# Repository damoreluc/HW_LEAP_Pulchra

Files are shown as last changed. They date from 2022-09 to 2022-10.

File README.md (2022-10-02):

# HW_LEAP_Pulchra
File del progetto HW Leap Pulchra

## Scheda della stazione meteo con Arduino MKRWAN1310

__Connettori:__

* X1: direzione vento (X1-1: +3V3; X1-2: tensione analogica tra 0V e +3V3; X1-3: GND)
* X2: anemometro (X2-1: +3V3; X2-2: impulsi, open drain; X2-3: GND)
* X3: alimentazione +3V3 (X3-1: +3V3; X3-2: GND)
* X4: pluviometro (X4-1: +3V3; X4-2: impulsi bilancere, open drain; X4-3 +12V riscaldatore neve; X4-4: GND riscaldatore neve)
* X5: alimentazione +12V (X5-1: +12V; X5-2: GND)
* X6: ventola interna all'armadietto (X6-1: +12V; X6-2: comando PWM ventola, collettore transistor Q1)
* X8: sensore bagnatura foglia (X8-1: +3V3; X8-2: on/off, open drain; X8-3; GND)

---

__Componenti e sensori integrati onboard:__
* U1: scheda microcontrollore e radio MKRWAN1310
* U2: modulo condizionamento per sensore esterno di temperatura PT100, ADAFRUIT_MX31865
* U3: (opzionale) sensore temperatura e umidità interno BME280
* U4: (opzionale) display oled SSD1306_128X64
* U5: (opzionale) sensore di temperatura interna analogico TMP36

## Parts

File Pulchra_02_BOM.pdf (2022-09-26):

26/09/22, 18:47 | Pulchra_02_BOM.html
file:///C:/Users/luca/Documents/EAGLE/projects/PULCHRA/Pulchra_02/Pulchra_02_BOM.html | 1/1

Partlist exported from C:/Users/luca/Documents/EAGLE/projects/PULCHRA/Pulchra_02/Pulchra_02.sch at 26/09/2022 18:45

Qty Value | Device | Package | Parts Description | MF | MPN | OC_FARNELL OC_NEWARK POPULARITY SPICEPREFIX
1 | 1.5K | R-EU_0207/10 | 0207/10 | R3 | RESISTOR, European symbol | 81 | R
2 | 100nF | C-EU050-025X075 | C050-025X075 | C1,
| | | | C2 | CAPACITOR, European symbol | 29 | C
1 | 10K | R-EU_0207/10 | 0207/10 | R11 RESISTOR, European symbol | 81 | R
3 | 12K | R-EU_0207/10 | 0207/10 | R1,
| | | | R2,
| | | | R6 | RESISTOR, European symbol | 81 | R
1 | 1N4004 | 1N4004 | DO41-10 | D2 | DIODE | 82
1 | 1N5819-B | 1N5819-B | DO41-7.6 | D1 | 1.0A SCHOTTKY BARRIER
| | | | | RECTIFIER | 11
1 | 33K | R-EU_0207/10 | 0207/10 | R4 | RESISTOR, European symbol | 81 | R
1 | 470nF | C-EU050-025X075 | C050-025X075 | C3 | CAPACITOR, European symbol | 29 | C
1 | ADAFRUIT_MX31865 ADAFRUIT_MX31865 ADAFRUIT_MAX31865 U$2
| | | | | Adafruit MAX31865 - Adafruit
| | | | | MAX31865 RTD PT100 or
| | | | | PT1000 Amplifier
1 | BD677 | BD677 | TO126 | Q1 | NPN Darlington Transistor | 0
1 | BME280 | BME280 | BME280_GYBMEP | U$3
1 | MKRWAN1310 | MKRWAN1310 | MKRWAN1310 | U$1 Arduino MKR WAN 1310 -
| | | | | Code: MKRWAN1310WANT
1 | MOUNT-PAD-
| ROUND4.1 | MOUNT-PAD-
| | ROUND4.1 | 4,1-PAD | H1 | MOUNTING PAD, round | 0
3 | MST2V | MST2V | MSTBV2 | X3,
| | | | X5,
| | | | X6
PHOENIX | unknown | unknown | 0
3 | MSTBA3 | MSTBA3 | MSTBA3 | X1,
| | | | X2,
| | | | X8
PHOENIX | FARNELL 1757255 3705183 | 71C4162 | 3
1 | MSTBV4 | MSTBV4 | MSTBV4 | X4 | PHOENIX

MSTBV
2,5/4-GF-5.08
1792794 | 69R9847 | 2
1 | SSD1306_128X64 | SSD1306_128X64 | 128X64 | U$4 | OLED Display Board 0.91"
| | | | | 128x64 White I2C - 4 Pins -
| | | | | SSD1306
1 | TMP36 | TMP36 | TO92 | U$5 | TMP35, TMP36, TMP37 - low
| | | | | voltage, precision centigrade
| | | | | temperature sensors

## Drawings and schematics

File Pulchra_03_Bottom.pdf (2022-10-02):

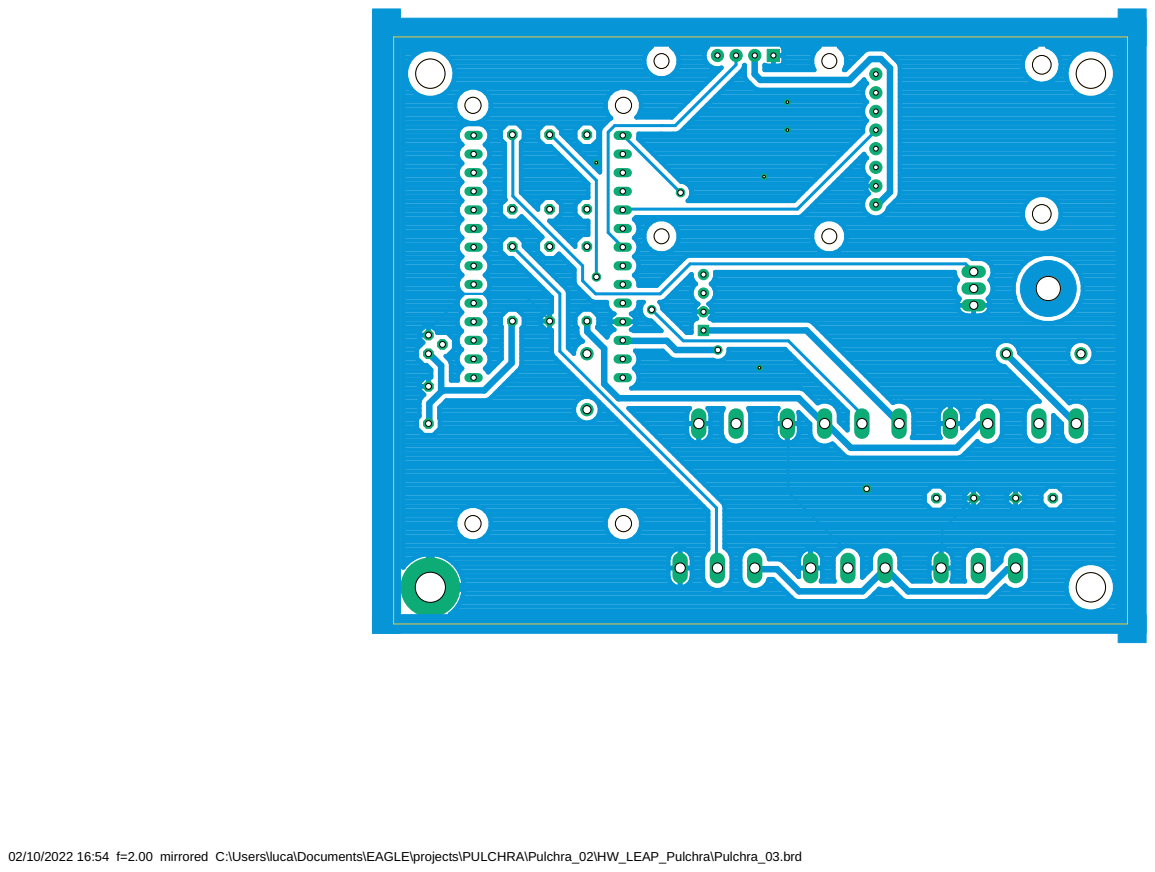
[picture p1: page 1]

02/10/2022 16:54 f=2.00 mirrored C:\Users\luca\Documents\EAGLE\projects\PULCHRA\Pulchra_02\HW_LEAP_Pulchra\Pulchra_03.brd

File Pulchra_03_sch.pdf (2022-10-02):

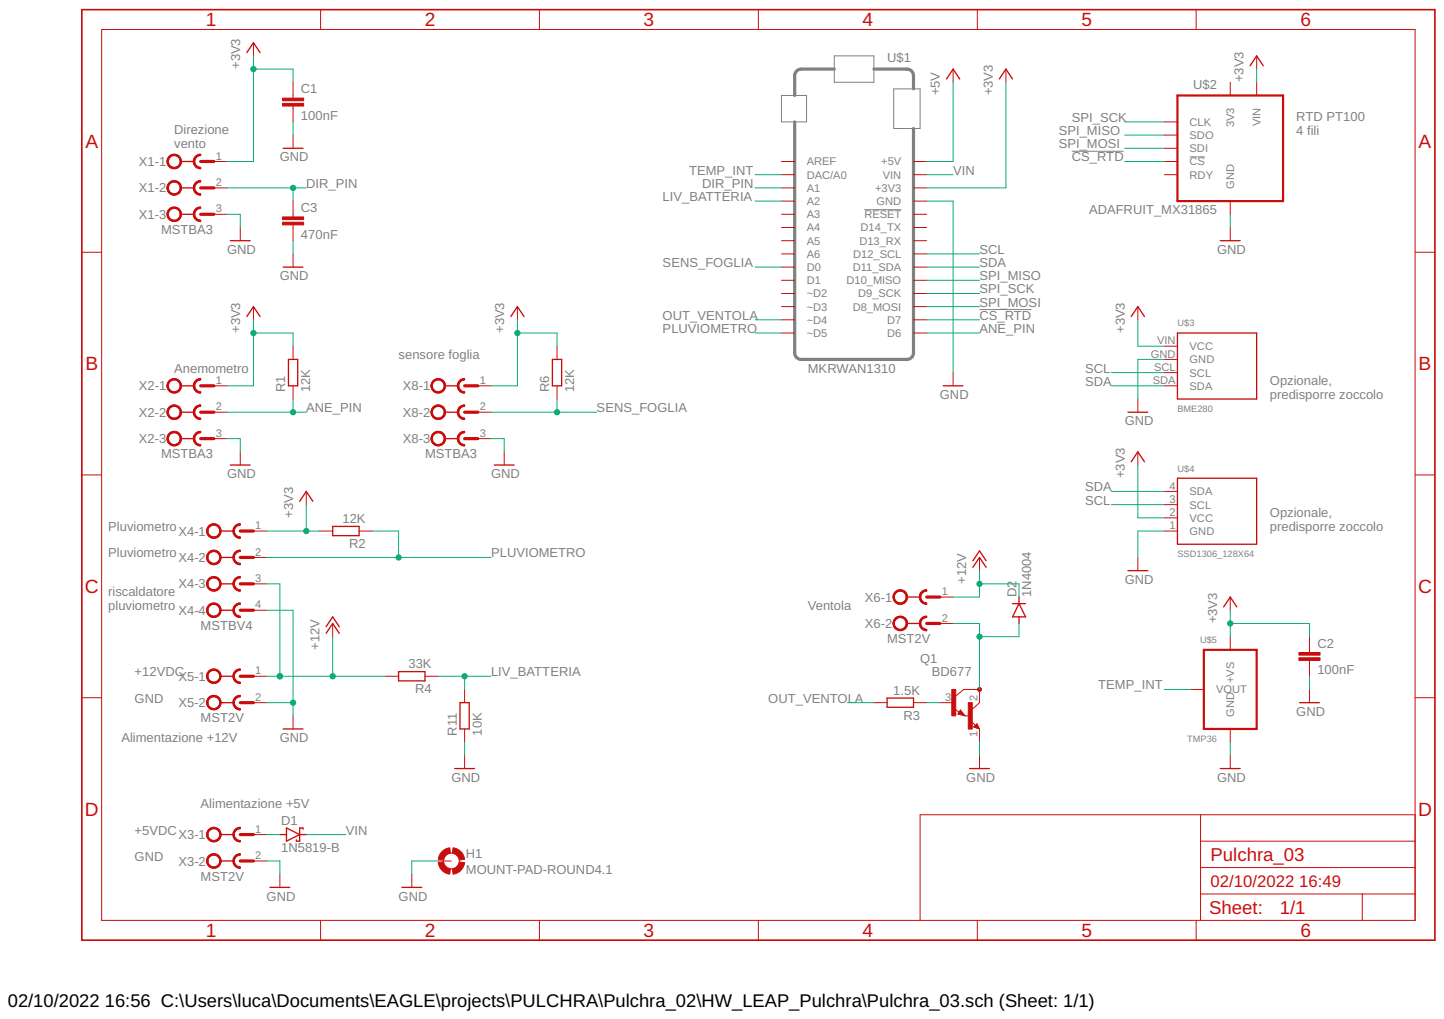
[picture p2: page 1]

Opzionale, predisporre zoccolo

02/10/2022 16:56 C:\Users\luca\Documents\EAGLE\projects\PULCHRA\Pulchra_02\HW_LEAP_Pulchra\Pulchra_03.sch (Sheet: 1/1)

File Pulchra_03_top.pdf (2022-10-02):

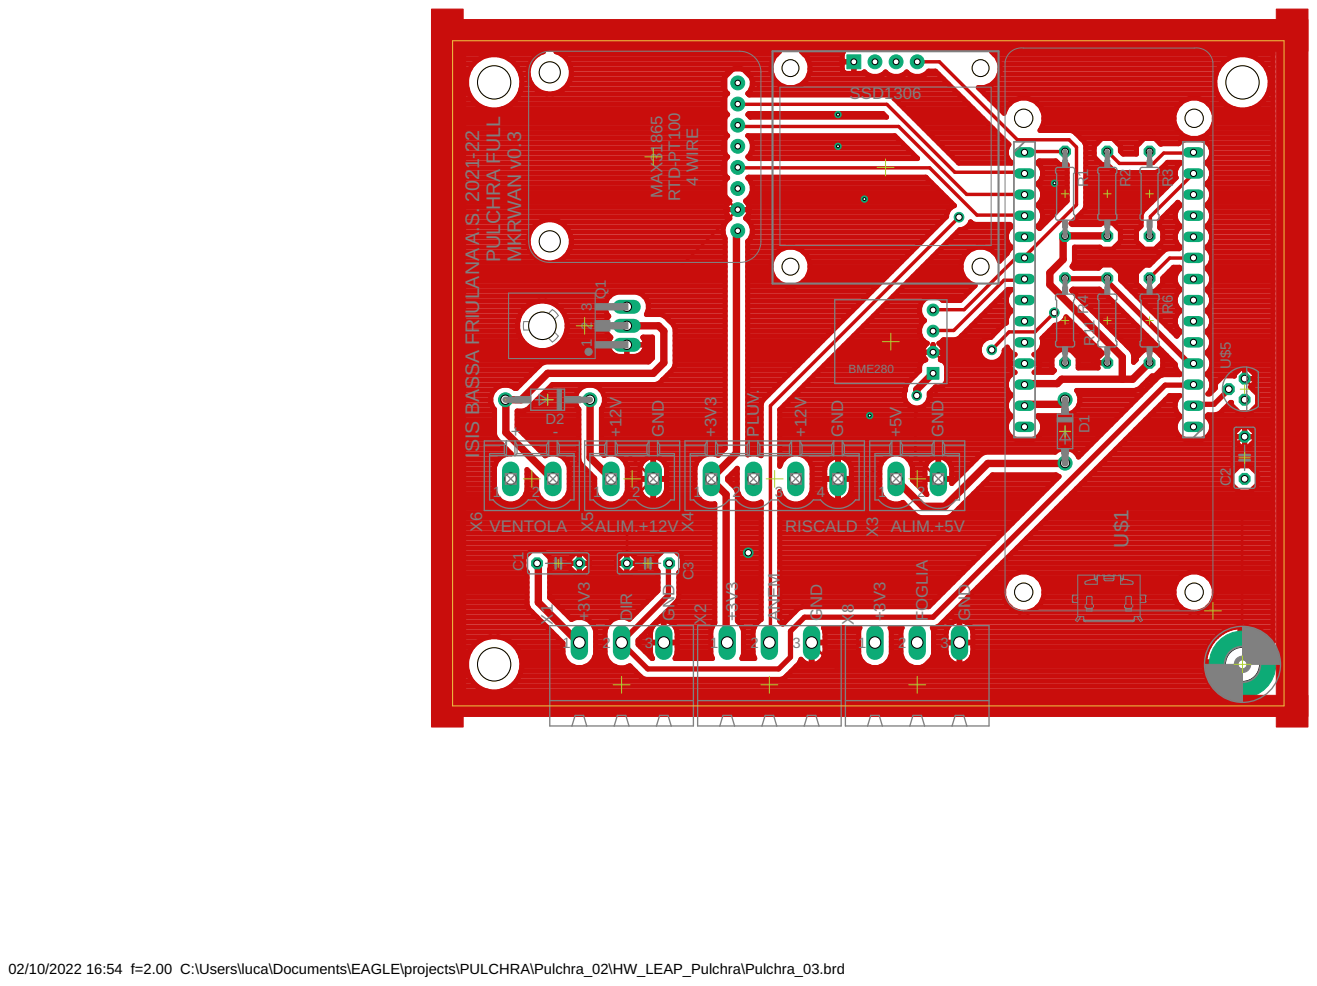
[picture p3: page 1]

02/10/2022 16:54 f=2.00 C:\Users\luca\Documents\EAGLE\projects\PULCHRA\Pulchra_02\HW_LEAP_Pulchra\Pulchra_03.brd

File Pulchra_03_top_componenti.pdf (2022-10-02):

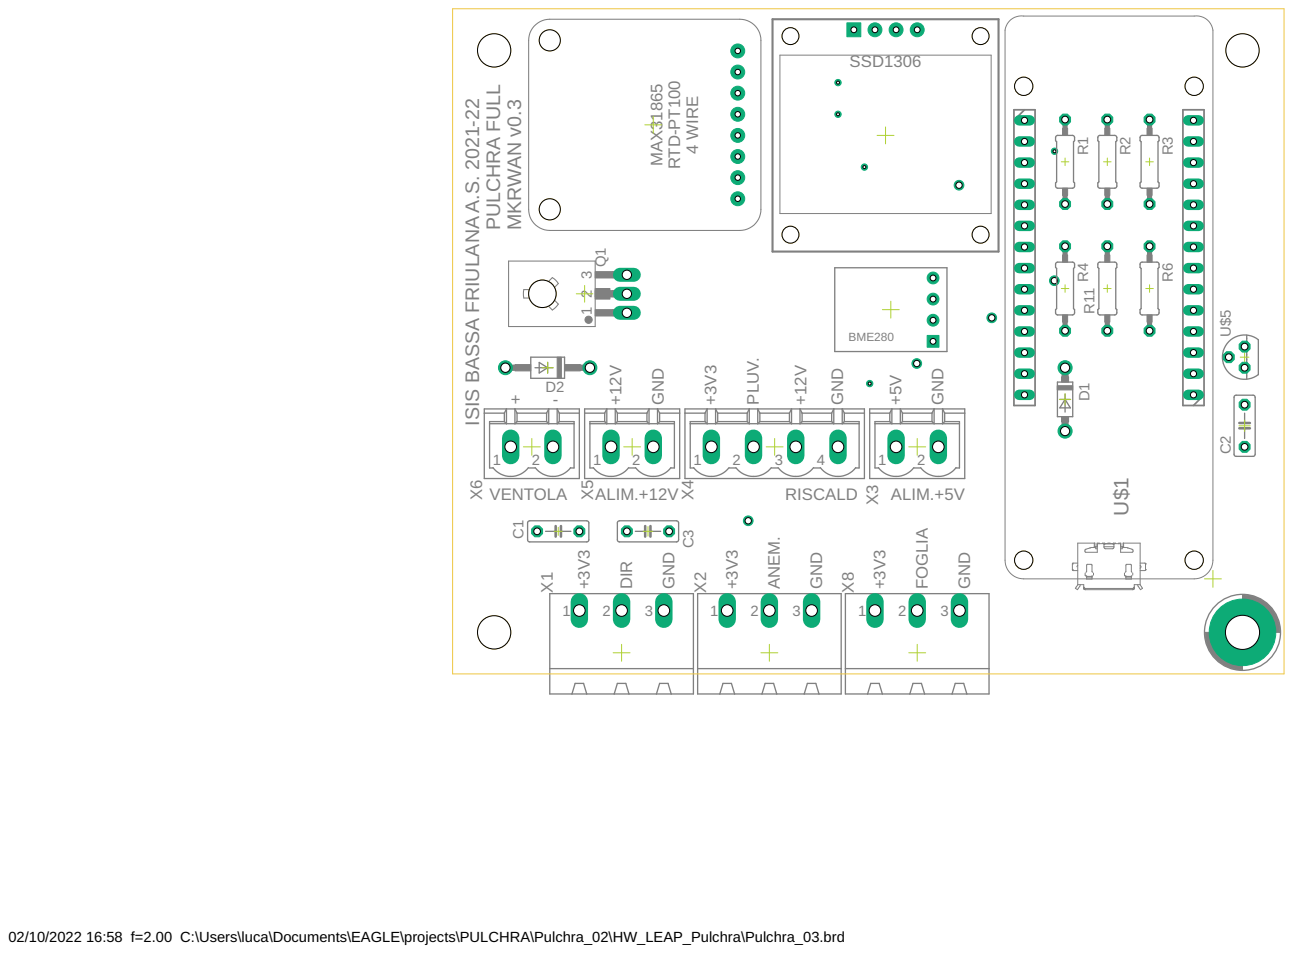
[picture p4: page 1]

02/10/2022 16:58 f=2.00 C:\Users\luca\Documents\EAGLE\projects\PULCHRA\Pulchra_02\HW_LEAP_Pulchra\Pulchra_03.brd

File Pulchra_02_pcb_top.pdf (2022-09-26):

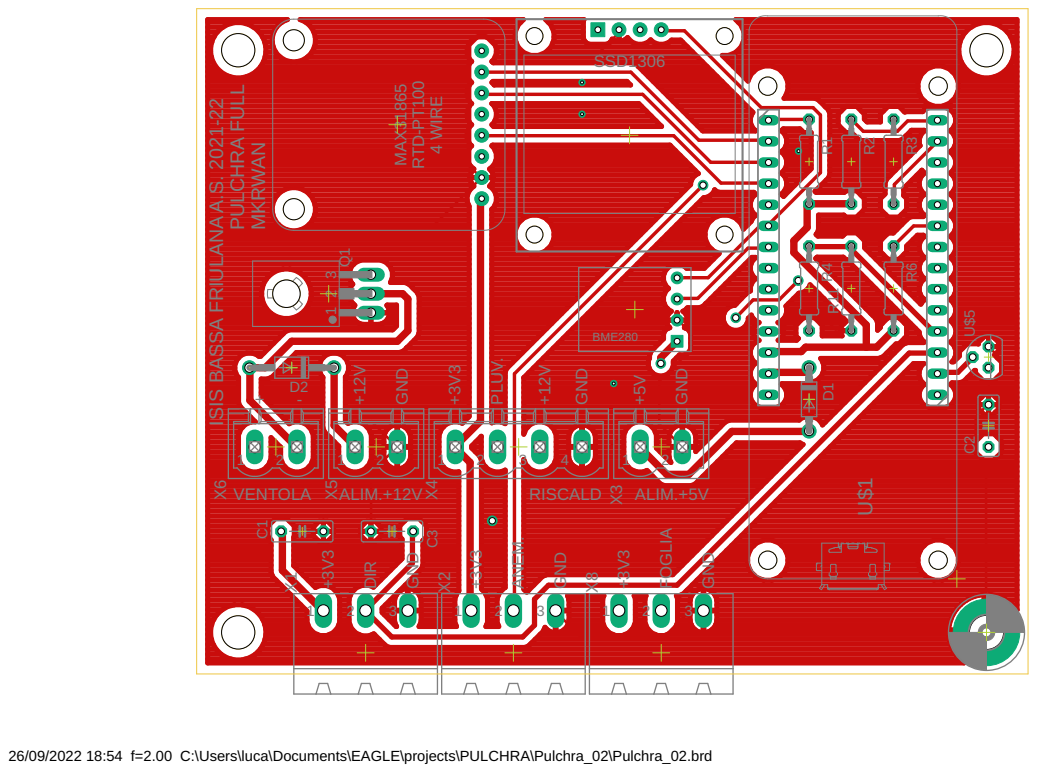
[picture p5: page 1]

26/09/2022 18:54 f=2.00 C:\Users\luca\Documents\EAGLE\projects\PULCHRA\Pulchra_02\Pulchra_02.brd

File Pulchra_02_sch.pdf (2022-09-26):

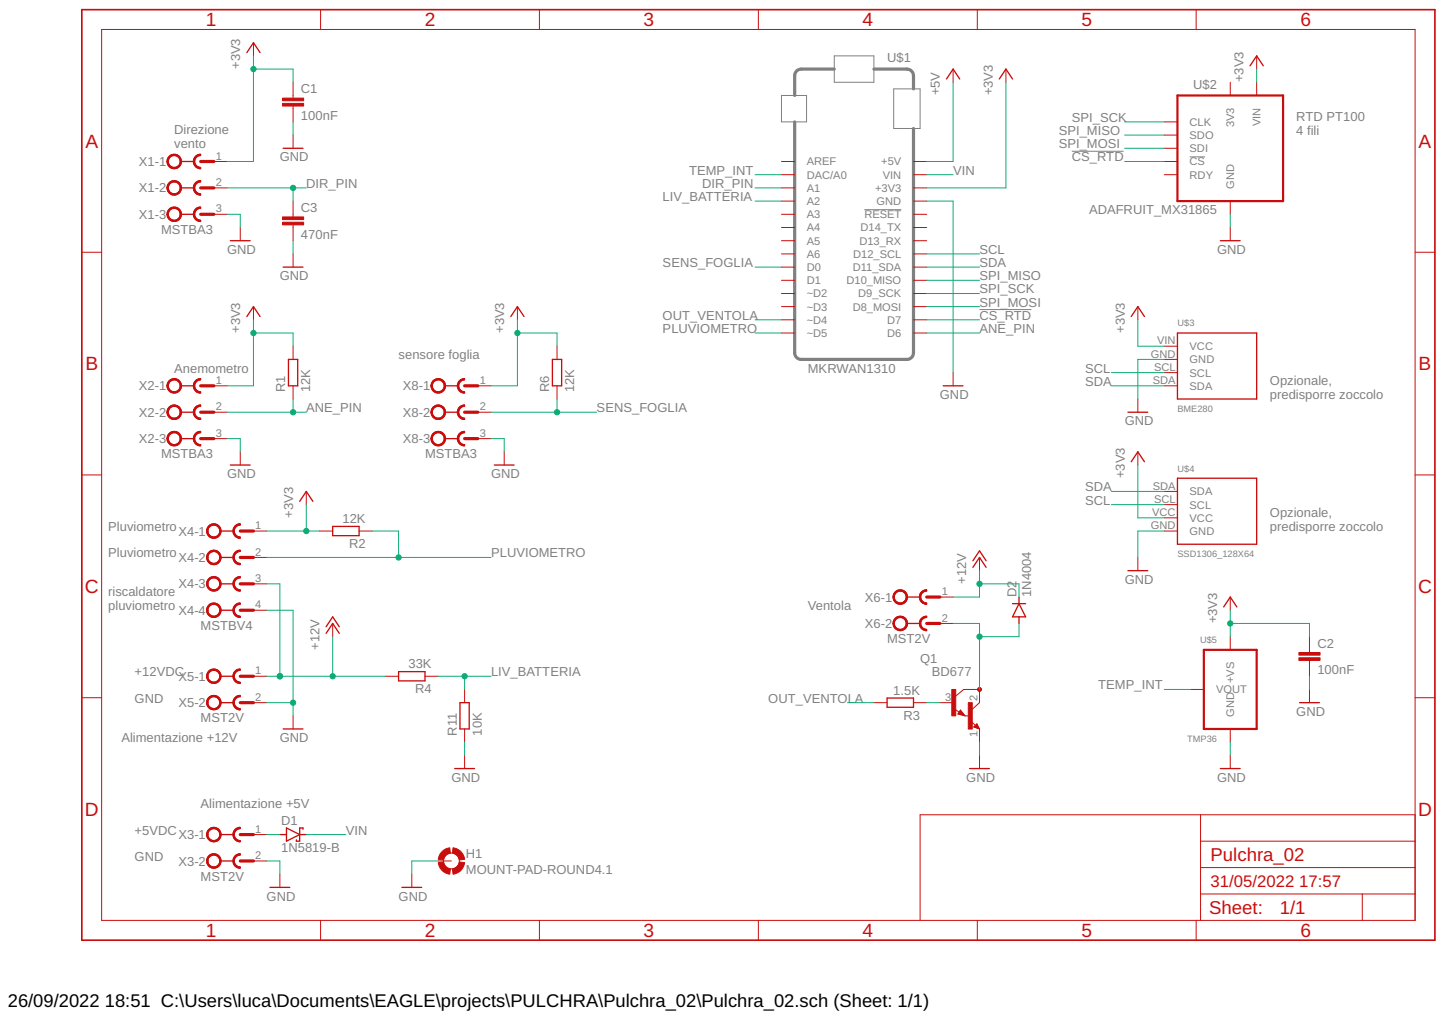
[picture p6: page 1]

Opzionale, predisporre zoccolo

26/09/2022 18:51 C:\Users\luca\Documents\EAGLE\projects\PULCHRA\Pulchra_02\Pulchra_02.sch (Sheet: 1/1)

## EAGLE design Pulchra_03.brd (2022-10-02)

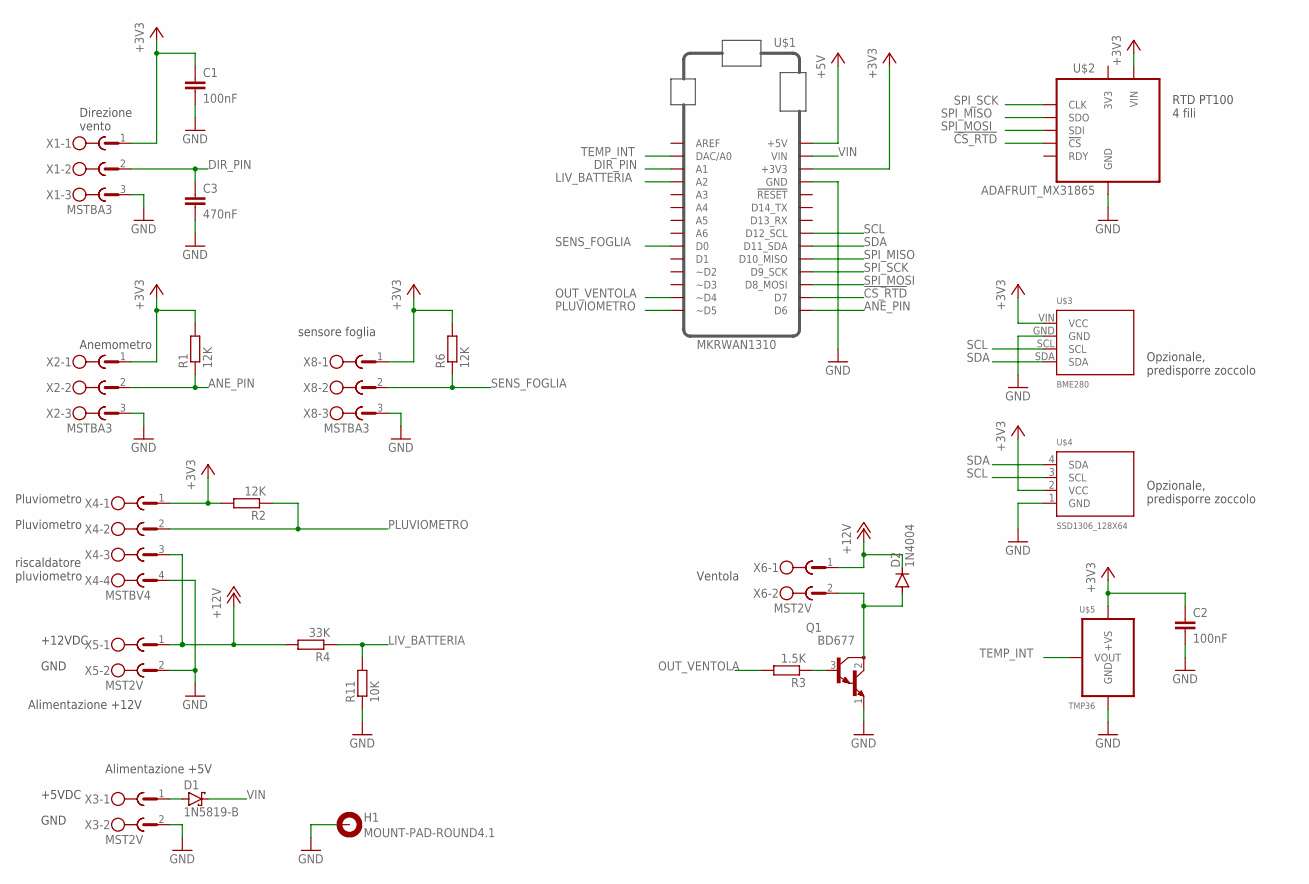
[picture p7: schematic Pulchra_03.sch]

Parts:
C1, C2: 100nF; C050-025X075
C3: 470nF; C050-025X075
D1: 1N5819-B; DO41-7.6
D2: 1N4004; DO41-10
H1: MOUNT-PAD-ROUND4.1; 4,1-PAD
Q1: BD677; TO126
R1, R2, R6: 12K; 0207/10
R3: 1.5K; 0207/10
R4: 33K; 0207/10
R11: 10K; 0207/10
U$1: MKRWAN1310
U$2: ADAFRUIT_MX31865; ADAFRUIT_MAX31865
U$3: BME280; BME280_GYBMEP
U$4: SSD1306_128X64; 128X64
U$5: TMP36; TO92
X1, X2, X8: MSTBA3
X3, X5, X6: MST2V; MSTBV2
X4: MSTBV4

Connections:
!CS_RTD!: U$1.D7, U$2.P7 (!CS!)
+3V3: C1.1, C2.1, R1.2, R2.2, R6.2, U$1.+3V3, U$2.P1 (VIN), U$3.VIN (VCC), U$4.2 (VCC), U$5.1 (+VS), X1.1, X2.1, X4.1, X8.1
+5V: U$1.+5V
+12V: D2.C, R4.2, X4.3, X5.1, X6.1
ANE_PIN: R1.1, U$1.D6, X2.2
DIR_PIN: C3.1, U$1.A1, X1.2
GND: C1.2, C2.2, C3.2, H1.B4,1, Q1.1 (E), R11.1, U$1.GND, U$2.P2 (GND), U$3.GND, U$4.1 (GND), U$5.3 (GND), X1.3, X2.3, X3.2, X4.4, X5.2, X8.3
LIV_BATTERIA: R4.1, R11.2, U$1.A2
unnamed: Q1.3 (B), R3.1
unnamed: D1.A, X3.1
unnamed: D2.A, Q1.2 (C), X6.2
OUT_VENTOLA: R3.2, U$1.~D4
PLUVIOMETRO: R2.1, U$1.~D5, X4.2
SCL: U$1.D12_SCL, U$3.SCL, U$4.3 (SCL)
SDA: U$1.D11_SDA, U$3.SDA, U$4.4 (SDA)
SENS_FOGLIA: R6.1, U$1.D0, X8.2
SPI_MISO: U$1.D10_MISO, U$2.P5 (SDO)
SPI_MOSI: U$1.D8_MOSI, U$2.P6 (SDI)
SPI_SCK: U$1.D9_SCK, U$2.P4 (CLK)
TEMP_INT: U$1.DAC0/A0 (DAC/A0), U$5.2 (VOUT)
VIN: D1.C, U$1.VIN

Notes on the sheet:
Opzionale, predisporre zoccolo
Direzione vento
Anemometro
Alimentazione +5V
Pluviometro
Ventola
sensore foglia
Alimentazione +12V
+5VDC
+12VDC
GND
RTD PT100 4 fili
riscaldatore pluviometro

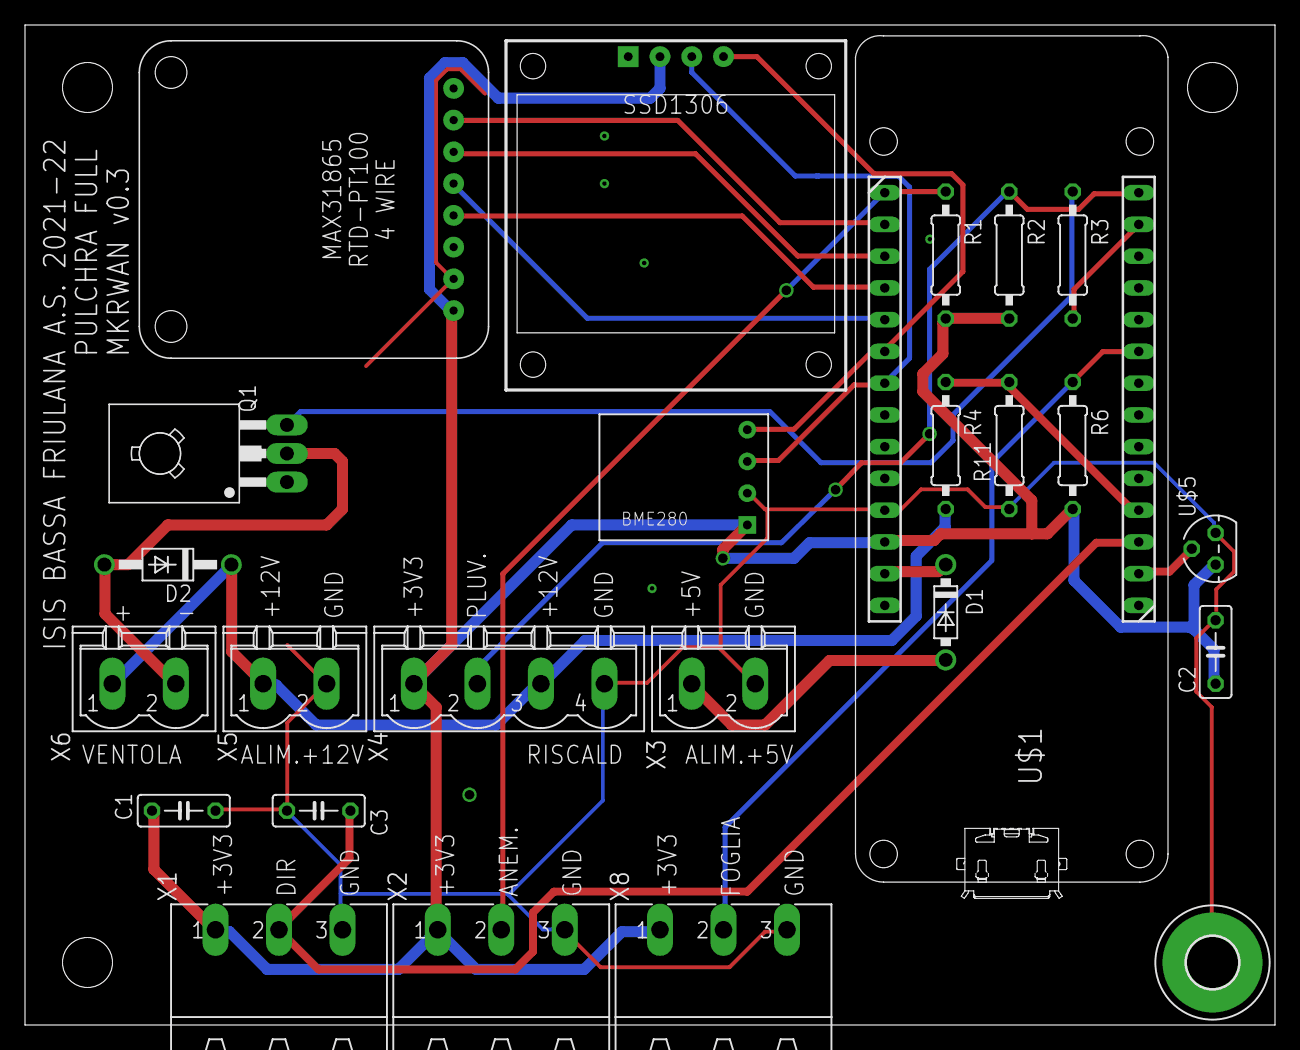
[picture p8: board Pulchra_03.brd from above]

Board: 2 copper layers, 100.0 x 80.0 mm, 25 parts (0 on the bottom side), 20 nets.

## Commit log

2022-09-26 versione base
    [Pulchra_02.brd, Pulchra_02.sch]
2022-10-02 Corretto SSD1306
    [Pulchra_03.brd, Pulchra_03.sch]
